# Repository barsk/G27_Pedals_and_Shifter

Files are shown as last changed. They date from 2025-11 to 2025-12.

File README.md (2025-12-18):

# Logitech G27/G29/G920/G923 Pedals and Shifter USB Adapter
*@barsk has taken over as maintainer of this repo after @n-e-y-s. This repo is forked from @functionruturnfunction, https://github.com/functionreturnfunction/G27_Pedals_and_Shifter.*

An USB adapter for the pedals and shifter to bypass the wheel base and treat them as a standalone device. G29/G920/G923 pedals should also work as the DB9 pinout is reportedly the same. Please use the discussions section to **report** wether it works or not with the G29 and later pedals, thanks!

The Logitech Driving Force Shifter used for G29 and later may be supported later, work in progress.

## Latest developments
* The Dpad is now supported as a proper Hat switch (8 directions), instead of 4 buttons!
* Throttle, brake and clutch now uses the axis Rx, Ry and Z so that the joystick control panel test view in Windows presents these in a better way. That has no impact in games as you can map any axis as throttle, brake and clutch.
* A 3D printed box is included in the CAD folder. Use the 3MF file version of the lid if you have a multi color capable printer for a nice text effect. The STL version prints a solid lid with no text.

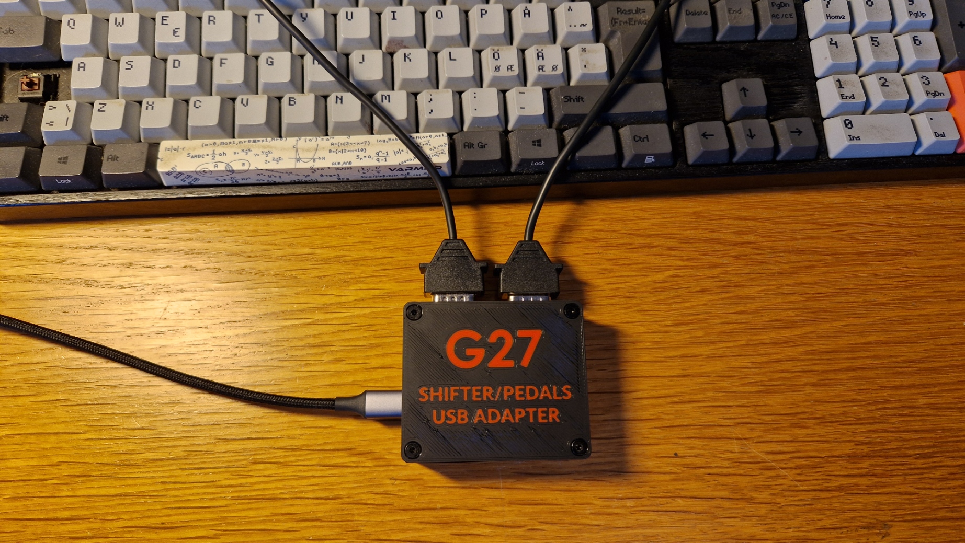
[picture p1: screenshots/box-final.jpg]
printed box

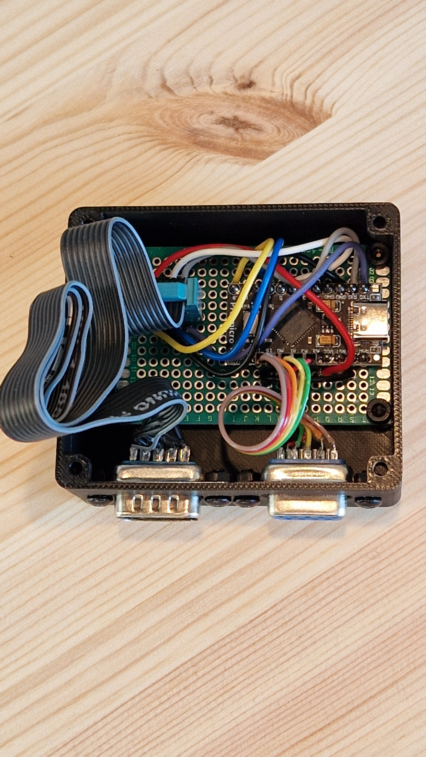
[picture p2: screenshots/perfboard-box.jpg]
on breadboard


Original (older) solution<br>
in altoids tin

## Required Parts/Materials

* [SparkFun Pro Micro](https://www.sparkfun.com/products/12640) or clone (must be a 5V/16MHz ATmega32U4 with onboard USB)
* [DB9 Connectors](http://www.amazon.com/Female-Male-Solder-Adapter-Connectors/dp/B008MU0OR4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), 1 male, 1 female
* Hookup wire in assorted colors
* Some kind of project box. The new 3D printed box or something as an Altoids tin box.
* The 3D printed box requires the use of a common perfboard type I got on Amazon, which is 60 x 40 mm with 20 rows by 14 columns of holes.

## Assembly

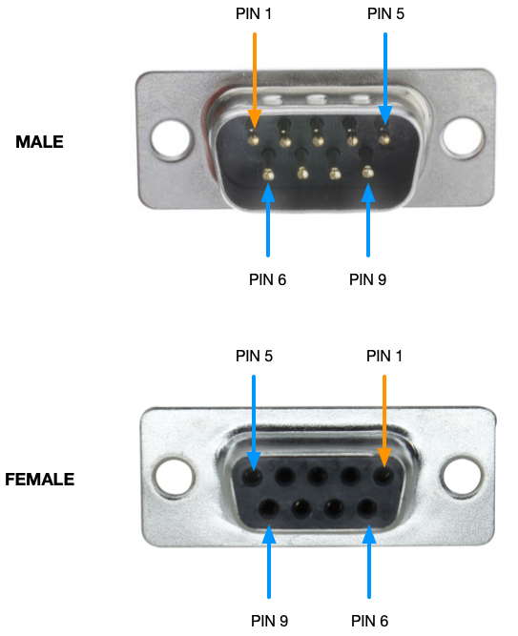
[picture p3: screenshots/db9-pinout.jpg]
DB9 pins


Connect the DB9 pin -> Pro Micro Pin as indicated below.

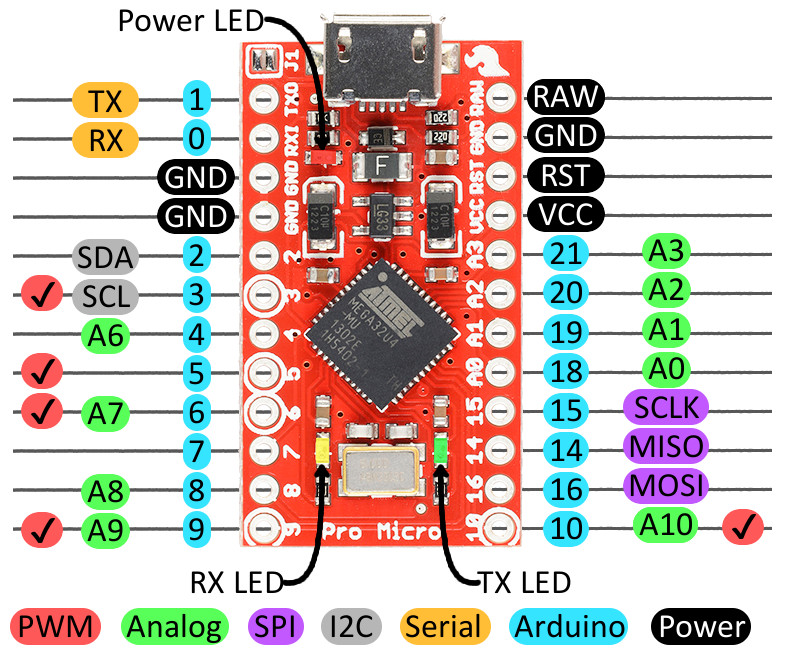
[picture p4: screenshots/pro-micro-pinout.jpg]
  

> [!Note]
> TX**0** = pin **1** and RX**1** = pin **0** on the Pro Micro come in confusing order! Easy to swap those wires!!

### Shifter pins (Male connector)
| DB9 | Color | Shifter | Description | Pro Micro |
| --- | --- | --- | --- | --- |
| 1 | purple | 1 | Button Clock | pin 0  (RX1) |
| 2 | grey | 7 | Button Data | pin 1  (TX0) |
| 3 | white | 5 | Button !CS & !PL (Mode) | pin 4 |
| 4 | blue | 3 | Shifter X axis | pin 8  (A8) |
| 5 | green | 2 | SPI input | |
| 6 | black | 8 | GND | GND |
| 7 | brown | 6 | +5V | VCC |
| 8 | yellow | 4 | Shifter Y axis | pin 9 (A9)  |
| 9 | red | 1 | +5V | VCC |

### Pedal pins (Female connector)
This is the updated wiring suggested by eriknz, which has proper connections to Vcc and GND.<br>
The pedals need to be inverted in the calibration gui.

Connect the female DB9 connector for the pedals to the board using the pins in the table.
| DB9 | Color | Description | Pro Micro |
| --- | --- | --- | --- |
| 1 | black | GND | GND |
| 2 | orange | Throttle | pin 18 (A0) |
| 3 | yellow | Brake | pin 19 (A1) |
| 4 | green | Clutch | pin 20 (A2) |
| 5 | | | |
| 6 | connected *in pedals* plug to pin 9 | (+5V) | |
| 7 | | | |
| 8 | | | |
| 9 | red | +5V | +5V |

## Perfboard and wiring
If a perfboard is used, which is required to fit the 3D printed box, mount the Micro Pro microprocessor board at the topmost row on the 4th column from the left. That will center the USB connector with the hole in the box. Then use the suggested wiring schematic or come up with your own. 

The Fritzing sketch makes the DB9 pins not so clear, which makes this a bit unreadable unfortunately. The important thing here is that the DB pins are connected to the Micro Pro pins in accordance with the table. However the position of the Pro Micro in refrence to the perfboard is physically correct - and should be used if you want to use the printed 3D box.<br>
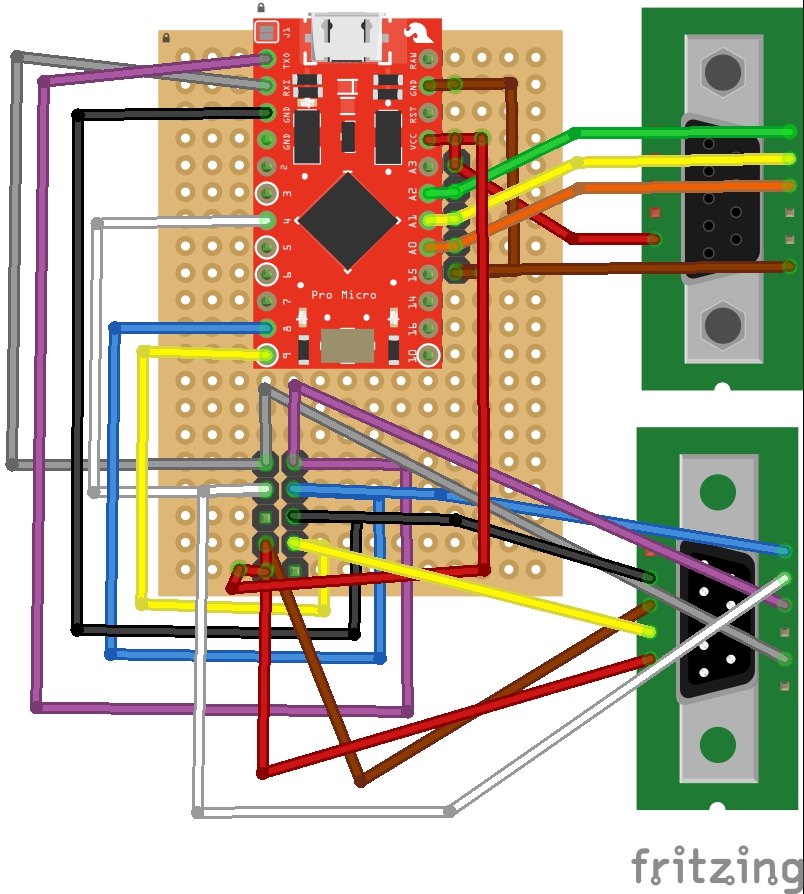
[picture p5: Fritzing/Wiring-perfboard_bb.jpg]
fritzing

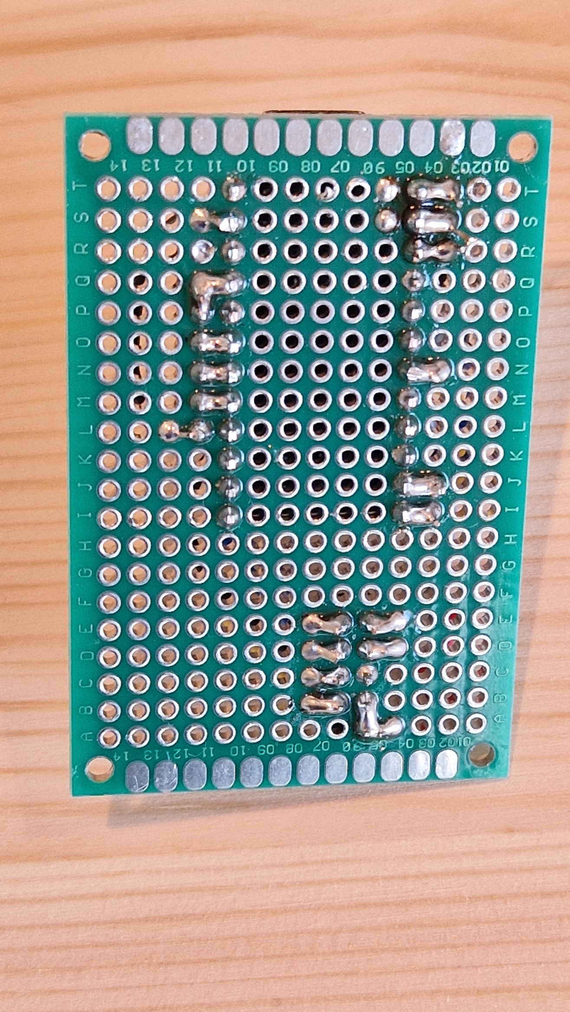
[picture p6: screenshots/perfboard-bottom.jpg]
soldering


## Firmware

Open the .ino file in the Arduino IDE, select the proper board type and COM port under "Tools" (you will need to install the [SparkFun board library](https://github.com/sparkfun/Arduino_Boards)). Also install the Arduino Joystick from MHeironimus.

## Calibration and Configration

After the firmware has been uploaded to the arduino, you want to calibrate and configure the device for your specific device. There is a python based graphical user interface available in this project. 

### GUI installation

#### Using binary releases (windows only)

The easiest method is to download g27calib.zip from the latest release here https://github.com/barsk/G27_Pedals_and_Shifter/releases/latest. Unzip this to a location of your choice and then start g27calib.exe located inside. 

#### Alterantively use python directly

This description assumes a windows operating system (other operating systems are similar; I have tested linux and windows). You need python3 for running this GUI - if you don't have a python3 interpreter on your system already, I suggest to get the interpreter at http://winpython.github.io/. I'd choose the minimal python 3.7 64 bit version, but other versions or distributions should also work. 

The python file *g27calib.py* is in the folder [g27_pedals_and_shifter_gui](g27_pedals_and_shifter_gui). If you have the required libraries installed in Python you may start the tool with:
    
    python g27calib.py

If the tool starts and works, you may also build the .exe (same as in the binary release). First make sure *Pyinstaller* is available and then run Pyinstaller on the supplied spec file.

    pip install pyinstaller
    pyinstaller g27calib.spec

This will create the g27.exe file in the dist subfolder.

#### Other methods
> [!Note]
> This chapter remain from the previous fork and has not been verified by me. I suggest you use the binary release.

When you have a python interpreter in place, I suggest to create a virtual environment using the shell commands:
    
    cd <a path of your choice>
    python -m venv g27calib

This command creates a virtual python environment in the directory g27calib. Afterwards you can install the GUI with 

    .\g27calib\Scripts\pip install git+https://github.com/barsk/G27_Pedals_and_Shifter@master#egg=G27_Pedals_and_Shifter_GUI

Of course you can also specify a local path alternatively to the git path above. Pip downloads some packages from the internet and finally you should be able to start

    g27calib/Scripts/g27calib
    
and the gui should open.

### Calibration process

At first you need to select the Arduino serial device. On linux platforms, it is also necessary to select the joystick device of the G27, otherwise the GUI might be very slow:

device selector

When everything is set correctly, press the Start button. You are presented with the calibration/configuration GUI:

gui screenshot

On the upper right, you get some help text about what to do next. Using that everything shall be pretty self-explaining. The graphs in the lower part are for the pedals and the shifter respectively. You see the measurements over the last second depicted with the "+" marks. 

> [!Note]
> When the GUI mentions you should "move" the shifter with the leftmost red button pressed, it means that the areas you are creating with those movements are the *target area* for the shifter positions. Make sure the areas are large enough to cover the position each gear may have as well as the idle postion, and that no area is too close to another to create a false detection.<br>
When a gear is moved into a target area that will trigger a virtual button to be pressed. Gear 1 pushes button 1 and so on.

The first step is to decide for a suitable filtering. Depending on the wear of your device, the measurements can be quite noisy and so it might be desirable to enable the median filtering in the options panel. When changing the values you will see the immediate effect on the measurements.

> [!Tip]
> If you see a noisy jittery signal from the pedals (and meybe also the shifter), a better solution that filtring is to clean the surfaces of the potentiometers with a can of electronics cleaner spray, which exists for this exact purpose. You will have to open up the casing in order to do get proper access to the potentiometers and spray a small amount inside the pots. I use a Finnish product called "Kontakt PRF 7-78", which cleans and lubricates the carbon surface perfectly, making it as new again and also causing it to have some protection from oxidating again (as it seems in my experience). There is another product called DeOxit that comes in different kinds. You specifically want the F5 one, and not one of the others as those are for connectors, not pots! Some more info here: [YouTube video(]https://www.youtube.com/watch?v=wFP0vSJexFQ)

Note the status line output in the GUI with some profiling output on the left side and the final output values of the axis, buttons and gear value as delivered to the games. 

Last step is to ***save the settings*** to the Arduino's EEPROM using the respective button. You can test that this has been working by going back to the default calibration (plots should change) and then reloading the EEPROM calibration (plots should change to the desired values). Everytime you turn on the Arduino it loads the EEPROM calibration values automatically from now on.

## Known issues
* (see here: https://github.com/n-e-y-s/G27_Pedals_and_Shifter/issues/1): On windows, the arduino will be slow after closing the GUI. To fix that, you can unplug the USB connector and then connect again.
* Since we now have implemented Dpad as a Hat switch, the former implementation that triggered the buttons 10-14 still remains, so those buttons are now "dead". This will not cause any problems, since each used button must be bound in-game anyway. I may fix this in a later release.

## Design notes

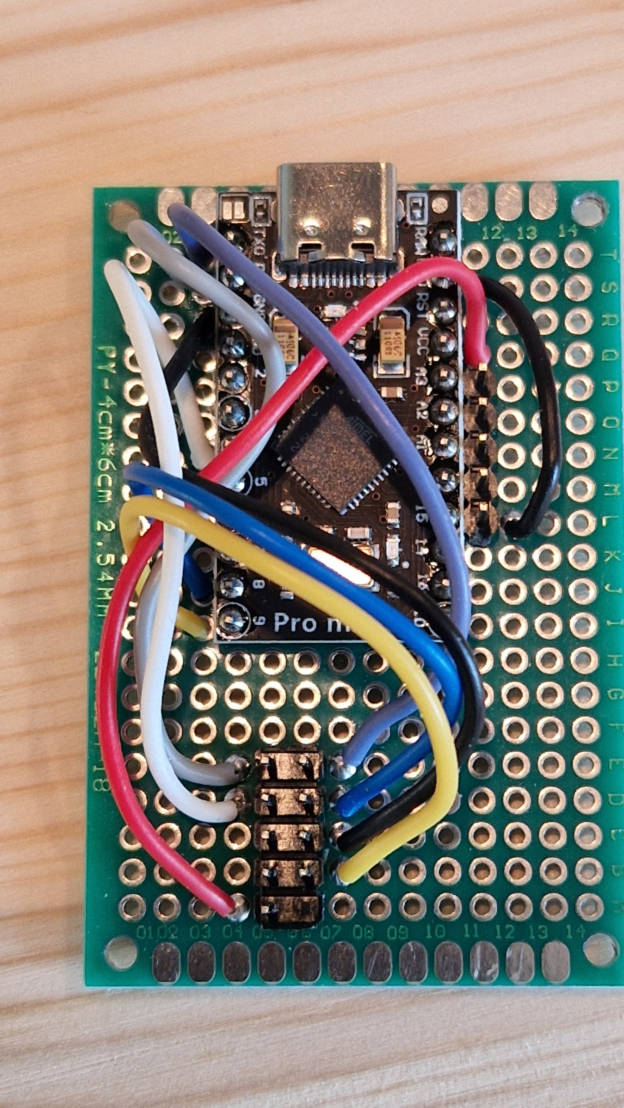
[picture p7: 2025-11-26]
screenshots/perfboard.jpg

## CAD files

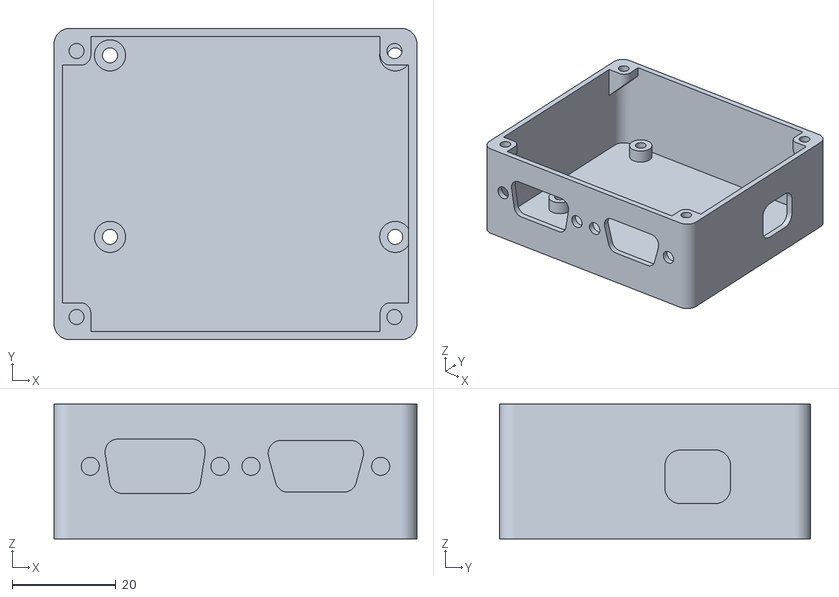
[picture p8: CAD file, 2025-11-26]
CAD/Box.stl
70.0 x 60.0 x 26.0

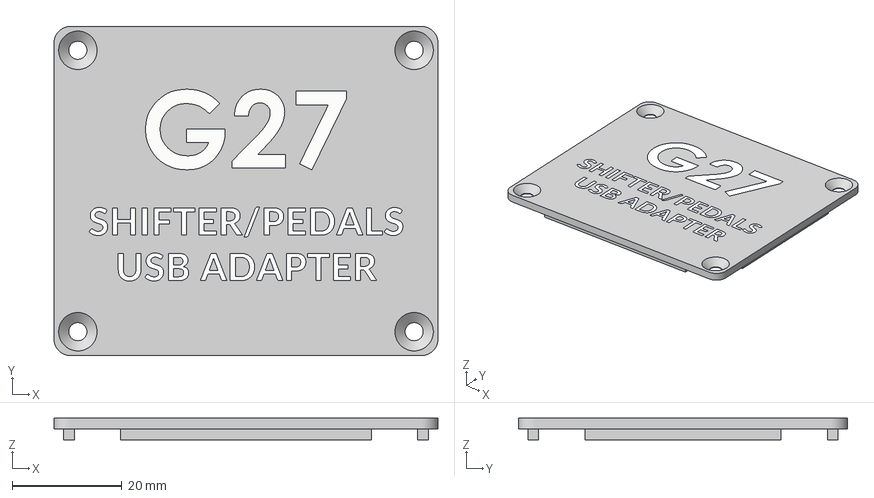
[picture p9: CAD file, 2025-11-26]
CAD/Lid.3mf
70.0 x 60.0 x 4.00 mm
Lid

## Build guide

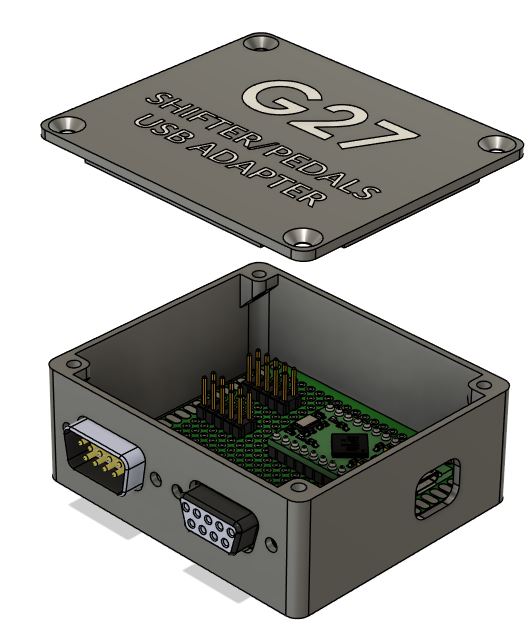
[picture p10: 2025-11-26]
screenshots/printed-box.jpg

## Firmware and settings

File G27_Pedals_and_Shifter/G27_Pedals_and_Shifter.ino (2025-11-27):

// G27_Pedals_and_Shifter.ino
// by Jason Duncan

// Partially adapted from the work done by isrtv.com forums members pascalh and xxValiumxx:
// http://www.isrtv.com/forums/topic/13189-diy-g25-shifter-interface-with-h-pattern-sequential-and-handbrake-modes/

#include <HID.h>
#include <EEPROM.h>
#include <Joystick.h>
#include "./src/Filter.h"

// LED PINS
#define RED_PIN    3
#define GREEN_PIN  5
#define BLUE_PIN   6

// PEDAL PINS - please note the comments of @eriknz in 
// https://github.com/n-e-y-s/G27_Pedals_and_Shifter/issues/8
// This is the wiring suggested by eriknz, which does not connect the pedal ground 
// to +5V (pedals need to be inverted in the calibration gui):
//
//| DB9 | Original | Harness | Description | Pro Micro   |
//|   1 | Black    | Black   | GND         | GND         |
//|   2 | Orange   | Yellow  | Throttle    | pin 18 (A0) |
//|   3 | White    | White   | Brake       | pin 19 (A1) |
//|   4 | Green    | Green   | Clutch      | pin 20 (A2) |
//|   5 |          |         |             |             |
//|   6 | connected in pedals plug to pin 9
//|   7 |          |         |             |             |
//|   8 |          |         |             |             |
//|   9 | Red      | Red     | +5V         | +5V         |
//
// This is the original wiring from @functionreturnfunction
//
//| DB9 | Original | Harness | Description | Pro Micro   |
//|   1 | Black    | Red     | +5v         | +5v         |
//|   2 | Orange   | Yellow  | Throttle    | pin 18 (A0) |
//|   3 | White    | White   | Brake       | pin 19 (A1) |
//|   4 | Green    | Green   | Clutch      | pin 20 (A2) |
//|   5 |          |         |             |             |
//|   6 | Red      | Black   | GND         | GND         |
//|   7 |          |         |             |             |
//|   8 |          |         |             |             |
//|   9 | Red      | Black   | GND         | GND         |
#define GAS_PIN    18
#define BRAKE_PIN  19
#define CLUTCH_PIN 20

// SHIFTER PINS
//| DB9 | Original | Harness | Shifter | Description             | Pro Micro   |
//|   1 | Purple   | Purple  |       1 | Button Clock            | pin 0       |
//|   2 | Grey     | Blue    |       7 | Button Data             | pin 1       |
//|   3 | Yellow   | Yellow  |       5 | Button !CS & !PL (Mode) | pin 4       |
//|   4 | Orange   | Orange  |       3 | Shifter X axis          | pin 8  (A8) |
//|   5 | White    | White   |       2 | SPI input               |             |
//|   6 | Black    | Black   |       8 | GND                     | GND         |
//|   7 | Red      | Red     |       6 | +5V                     | VCC         |
//|   8 | Green    | Green   |       4 | Shifter Y axis          | pin 9 (A9)  |
//|   9 | Red      | Red     |       1 | +5V                     | VCC         |
#define SHIFTER_CLOCK_PIN  0
#define SHIFTER_DATA_PIN   1
#define SHIFTER_MODE_PIN   4
#define SHIFTER_X_PIN      8
#define SHIFTER_Y_PIN      9

// BUTTON DEFINITIONS
#define BUTTON_REVERSE         1

#define BUTTON_RED_CENTERRIGHT 4
#define BUTTON_RED_CENTERLEFT  5
#define BUTTON_RED_RIGHT       6
#define BUTTON_RED_LEFT        7
#define BUTTON_BLACK_TOP       8
#define BUTTON_BLACK_RIGHT     9
#define BUTTON_BLACK_LEFT      10
#define BUTTON_BLACK_BOTTOM    11
#define BUTTON_DPAD_RIGHT      12
#define BUTTON_DPAD_LEFT       13
#define BUTTON_DPAD_BOTTOM     14
#define BUTTON_DPAD_TOP        15

// Gears are mapped to output 0-6

#define OUTPUT_BLACK_TOP       7
#define OUTPUT_BLACK_LEFT      8
#define OUTPUT_BLACK_RIGHT     9
#define OUTPUT_BLACK_BOTTOM    10
#define OUTPUT_DPAD_TOP        11
#define OUTPUT_DPAD_LEFT       12
#define OUTPUT_DPAD_RIGHT      13
#define OUTPUT_DPAD_BOTTOM     14
#define OUTPUT_RED_LEFT        15
#define OUTPUT_RED_CENTERLEFT  16
#define OUTPUT_RED_CENTERRIGHT 17
#define OUTPUT_RED_RIGHT       18

// MISC.
#define MAX_AXIS            1023
#define SIGNAL_SETTLE_DELAY 10

#define CALIB_DATA_MAGIC_NUMBER 0x27CA11B1 // change this when the struct definition changes

#define FLAG1_INVERT_BRAKE 0x1 // invert brake pedal
#define FLAG1_INVERT_GAS 0x2 // invert gas pedal
#define FLAG1_INVERT_CLUTCH 0x4 // invert clutch pedal
#define FLAG1_REVERSE_RIGHT_RED 0x8 // use right red button for reverse gear instead of the reverse sensor
#define FLAG1_COMBINE_Z_EQUALS_X_MINUS_Z 0x10 // combine clutch and gas
#define FLAG1_COMBINE_Z_EQUALS_Z_MINUS_X 0x20 // combine clutch and gas

#define FLAG2_ENABLE_PEDALS 0x1
#define FLAG2_BRAKE_DEAD_ZONE (0x2|0x4|0x8) // deadZone_percent = ((flag & FLAG2_BRAKE_DEAD_ZONE) >> 1)*2
#define FLAG2_GAS_DEAD_ZONE (0x10|0x20|0x40) // deadZone_percent = ((flag & FLAG2_GAS_DEAD_ZONE) >> 4)*2

#define FLAG3_ENABLE_SHIFTER 0x1
#define FLAG3_CLUTCH_DEAD_ZONE (0x10|0x20|0x40) // deadZone_percent = ((flag & FLAG3_CLUTCH_DEAD_ZONE) >> 4)*2

Joystick_ G27(            // define Joystick parameters
  5,  
  JOYSTICK_TYPE_JOYSTICK,      // type Joystick
  19, 1,                       // Button Count, Hat Switch Count
  false, false, true,               // X, Y, Z
  true,true,false,                  // Rx, Ry, Rz
  false,false,false,false,false);   // Throttle, Rudder, Accelerator, Brake, Steering 

typedef struct CalibData
{
  /* magic number, used for testing valid EEPROM content */
  uint32_t calibID;
  /* bool whether to automatically calibrate the pedals at a power cycle or use a static calibration */
  uint8_t pedals_auto_calib; 
  /* flag1, see the FLAG1_* defines for the meaning of the bits */
  uint8_t flag1;
  /* flag2, see the FLAG2_* defines for the meaning of the bits */
  uint8_t flag2;
  /* flag3, see the FLAG3_* defines for the meaning of the bits */
  uint8_t flag3;
  /* size of median filter to filter pedal values */
  uint8_t pedal_median_size;
  /* size of median filter to filter shifter values */
  uint8_t shifter_median_size;
  /* only meaningful if pedals_auto_calib is 0 */
  uint16_t gasMin, gasMax, brakeMin, brakeMax, clutchMin, clutchMax;
  /* defines the neutral zone of the y shifter hysteresis */
  uint16_t shifter_y_neutralMin, shifter_y_neutralMax;
  /* defines the 246R zone of the y shifter hysteresis, should be less than shifter_y_neutralMin */
  uint16_t shifter_y_246R_gearZone;
  /* defines the 135 zone of the y shifter hysteresis, should be greater than shifter_y_neutralMax */
  uint16_t shifter_y_135_gearZone;
  /* threshold for gears 1 and 2 of the x shifter, should be less than shifter_x_56 */
  uint16_t shifter_x_12;
  /* threshold for gears 5,6 and R of the x shifter, should be greater than shifter_x_12 */
  uint16_t shifter_x_56;  
} CalibData;

/* this structure holds the calibration data stored in EEPROM */
typedef struct calibration
{
    /* the actual calibration struct */
    CalibData data;
    /* CRC checksum */
    uint32_t crc;
} Calibration;

static Calibration calibDefault = {
    {
        CALIB_DATA_MAGIC_NUMBER,
        1, /* pedals auto calib */
        0, /* flag1, everything on default */
        1, /* use pedals */
        1, /* use shifter */
        0, /* pedals median size */
        0, /* shifter median size */
        0,0,0,0,0,0, /* calibrated pedal values */
        1024/2 - 1024/10, 1024/2 + 1024/10, /* shifter_y_neutral */
        1024/2 - 1024/3, 1024/2 + 1024/3,   /* shifter_y_gearZone */
        1024/3, 1024*2/3 /* shifter_x */
    },
    0 /* crc will be set when written to EEPROM */
};
static Calibration calibration = calibDefault;

unsigned long crc(uint8_t *buffer, uint16_t length) {

  const unsigned long crc_table[16] = {
    0x00000000, 0x1db71064, 0x3b6e20c8, 0x26d930ac,
    0x76dc4190, 0x6b6b51f4, 0x4db26158, 0x5005713c,
    0xedb88320, 0xf00f9344, 0xd6d6a3e8, 0xcb61b38c,
    0x9b64c2b0, 0x86d3d2d4, 0xa00ae278, 0xbdbdf21c
  };

  unsigned long crc = ~0L;

  for (uint8_t index = 0 ; index < length ; ++index) {
    crc = crc_table[(crc ^ buffer[index]) & 0x0f] ^ (crc >> 4);
    crc = crc_table[(crc ^ (buffer[index] >> 4)) & 0x0f] ^ (crc >> 4);
    crc = ~crc;
  }
  return crc;
}

static int crcError = 0;
static int magicNumberError = 0;
static int lastCrcFromEEPROM = 0;
static int lastCrcFromContents = 0;

void loadEEPROM()
{
  Calibration fromEEPROM;
  EEPROM.get(0, fromEEPROM);
  
  uint32_t eeprom_crc = crc((uint8_t*)&fromEEPROM.data, sizeof(fromEEPROM.data));
  lastCrcFromEEPROM = fromEEPROM.crc;
  lastCrcFromContents = eeprom_crc;
  if( eeprom_crc == fromEEPROM.crc && fromEEPROM.data.calibID == CALIB_DATA_MAGIC_NUMBER )
  {
    calibration = fromEEPROM;
  } else
  {
    crcError += eeprom_crc != fromEEPROM.crc;
    magicNumberError += fromEEPROM.data.calibID != CALIB_DATA_MAGIC_NUMBER;
    calibration = calibDefault;
  }
}

// PEDAL CODE
typedef struct Pedal {
  byte pin;
  int min, max, cur, axis;
} Pedal;

static Pedal* gasPedal = 0;
static Pedal* brakePedal = 0;
static Pedal* clutchPedal = 0;

int axisValue(struct Pedal* input, int dead_zone) 
{
  int physicalRange = input->max - input->min;
  int delta = dead_zone == 0 ? 0 : ((int32_t)physicalRange*(int32_t)dead_zone/(int32_t)100);
  int max = input->max - delta;
  int min = input->min + delta;
  physicalRange = max - min;
  if (physicalRange == 0) {
    return 0;
  }

  int result = map(input->cur, min, max, 0, MAX_AXIS);

  if (result < 0) {
    return 0;
  }
  if (result > MAX_AXIS) {
    return MAX_AXIS;
  }
  return result;
}

void processPedal(struct Pedal* input, SignalFilter *flt, uint8_t filterSize, int dead_zone) 
{
  input->cur = apply_filter(flt, filterSize, analogRead(input->pin));

  if(calibration.data.pedals_auto_calib)
  {
    // calibrate, we want the highest this pedal has been
    input->max = input->cur > input->max ? input->cur : input->max;
    // same for lowest, but bottom out at current value rather than 0
    input->min = input->cur < input->min ? input->cur : input->min;
  }

  input->axis = axisValue(input, dead_zone);
}

void setXAxis(void* in) {
  Pedal* input = (Pedal*)in;
  G27.setRxAxis(input->axis);
}

void setYAxis(void* in) {
  Pedal* input = (Pedal*)in;
  G27.setRyAxis(input->axis);
}

void setZAxis(void* in) {
  Pedal* input = (Pedal*)in;
  G27.setZAxis(input->axis);
}

// SHIFTER CODE
int buttonTable[] = {
  // first four are unused
  0, 0, 0, 0,
  OUTPUT_RED_CENTERRIGHT,
  OUTPUT_RED_CENTERLEFT,
  OUTPUT_RED_RIGHT,
  OUTPUT_RED_LEFT,
  OUTPUT_BLACK_TOP,
  OUTPUT_BLACK_RIGHT,
  OUTPUT_BLACK_LEFT,
  OUTPUT_BLACK_BOTTOM,
  OUTPUT_DPAD_RIGHT,
  OUTPUT_DPAD_LEFT,
  OUTPUT_DPAD_BOTTOM,
  OUTPUT_DPAD_TOP
};

void waitForSignalToSettle() {
  delayMicroseconds(SIGNAL_SETTLE_DELAY);
}

void getButtonStates(int *ret) {
  digitalWrite(SHIFTER_MODE_PIN, LOW);    // Switch to parallel mode: digital inputs are read into shift register
  waitForSignalToSettle();
  digitalWrite(SHIFTER_MODE_PIN, HIGH);   // Switch to serial mode: one data bit is output on each clock falling edge

  for(int i = 0; i < 16; ++i) {           // Iteration over both 8 bit registers
    digitalWrite(SHIFTER_CLOCK_PIN, LOW);         // Generate clock falling edge
    waitForSignalToSettle();

    ret[i] = digitalRead(SHIFTER_DATA_PIN);

    digitalWrite(SHIFTER_CLOCK_PIN, HIGH);        // Generate clock rising edge
    waitForSignalToSettle();
  }
}

void getShifterPosition(int *ret) {
  ret[0] = analogRead(SHIFTER_X_PIN);
  ret[1] = analogRead(SHIFTER_Y_PIN);
}

int getCurrentGear(int shifterPosition[], int btns[]) {
  static int gear = 0;  // default to neutral
  uint16_t x = shifterPosition[0], y = shifterPosition[1];
  
  if (y < calibration.data.shifter_y_neutralMax && y > calibration.data.shifter_y_neutralMin)
  {
    gear = 0;
  }

  if (y > calibration.data.shifter_y_135_gearZone )
  {
    if( x <= calibration.data.shifter_x_12 )
    {
      if( gear != 3 ) /* avoid toggles between neighboring gears */
      {
        gear = 1;
      }
    } else if ( x >= calibration.data.shifter_x_56 )
    {
      if( gear != 3 ) /* avoid toggles between neighboring gears */
      {
        gear = 5;
      }
    } else
    {
      if( gear != 1 && gear != 5 ) /* avoid toggles between neighboring gears */
      {
        gear = 3;
      }
    }
  }
  if (y < calibration.data.shifter_y_246R_gearZone )
  {
    if( x <= calibration.data.shifter_x_12 )
    {
      if( gear != 4 ) /* avoid toggles between neighboring gears */
      {
        gear = 2;
      }
    } else if ( x >= calibration.data.shifter_x_56 )
    {
      uint8_t reverse = (calibration.data.flag1 & FLAG1_REVERSE_RIGHT_RED) ? btns[BUTTON_RED_RIGHT] : btns[BUTTON_REVERSE];
      if(reverse)
      {
        if( gear != 4 && gear != 6 ) /* avoid toggles between neighboring gears */
        {
          gear = 7;
        }
      } else
      {
        if( gear != 4 && gear != 7) /* avoid toggles between neighboring gears */
        {
          gear = 6;
        }
      }
    } else
    {
      if( gear != 2 && gear != 6  && gear != 7) /* avoid toggles between neighboring gears */
      {
        gear = 4;
      }
    }
  }
  // reset button if we are not in reverse gear (this was there in original code, not sure if it's needed)
  if (gear != 7) btns[BUTTON_REVERSE] = 0;

  return gear;
}

typedef struct DebugStruct
{
  uint8_t sizeInBytes;
  uint8_t calibButton;
  int16_t axisValues[5];
  CalibData calib;
  uint16_t numCrcErrors;
  uint16_t numMagicNumErrors;
  uint32_t profiling[4];
  uint16_t out_axis[3];
  uint32_t out_buttons;
} DebugStruct;

static DebugStruct debug = {0};

void setButtonStates(int buttons[], int gear) {
  // SHIFTER CODE
  debug.out_buttons = 0;
  
  // release virtual buttons for all gears
  for (byte i = 0; i < 7; ++i) {
    G27.setButton(i, LOW);
  }

  if (gear > 0) {
    G27.setButton(gear - 1, HIGH);
    debug.out_buttons |= 1 << (gear - 1);
  }

  for (byte i = BUTTON_RED_CENTERRIGHT; i <= BUTTON_BLACK_BOTTOM; ++i) {
    G27.setButton(buttonTable[i], buttons[i]);
    if( buttons[i] )
    {
      debug.out_buttons |= 1 << buttonTable[i];
    }
  }

  // Hat switch (D-Pad)
  byte hatSwitchState = 0;
  hatSwitchState |= (buttons[BUTTON_DPAD_TOP] << 0);
  hatSwitchState |= (buttons[BUTTON_DPAD_RIGHT] << 1);
  hatSwitchState |= (buttons[BUTTON_DPAD_BOTTOM] << 2);
  hatSwitchState |= (buttons[BUTTON_DPAD_LEFT] << 3);

  switch (hatSwitchState)
  {
  case 0B00000001:
    G27.setHatSwitch(0, 0); // up
    break;
  case 0B00000011:
    G27.setHatSwitch(0, 45); // up right
    break;
  case 0B00000010:
    G27.setHatSwitch(0, 90); // right
    break;
  case 0B00000110:
    G27.setHatSwitch(0, 135); // down right
    break;
  case 0B00000100:
    G27.setHatSwitch(0, 180); // down
    break;
  case 0B00001100:
    G27.setHatSwitch(0, 225); // down left
    break;
  case 0B00001000:
    G27.setHatSwitch(0, 270); // left
    break;
  case 0B00001001:
    G27.setHatSwitch(0, 315); // up left
    break;
  case 0B00000000:
    G27.setHatSwitch(0, -1); // no direction
  default:
    break;
  }
}

void set_dead_zone(uint8_t dz, int pedal, CalibData *calib)
{
    dz /= 2;
    switch(pedal)
    {
        case 0:
            calib->flag2 &= ~(FLAG2_GAS_DEAD_ZONE);
            calib->flag2 |= (dz) << 4;
            break;
        case 1:
            calib->flag2 &= ~(FLAG2_BRAKE_DEAD_ZONE);
            calib->flag2 |= (dz) << 1;
            break;
        case 2:
            calib->flag3 &= ~(FLAG3_CLUTCH_DEAD_ZONE);
            calib->flag3 |= (dz) << 4;
            break;
        default:
          break;
    }
}

#define CALIB_MIN(calibValue, curValue, minValue) if( (int)calibValue < 0 || (int)curValue < (int)minValue ) { calibValue = minValue = curValue; }
#define CALIB_MAX(calibValue, curValue, maxValue) if( (int)calibValue < 0 || (int)curValue > (int)maxValue ) { calibValue = maxValue = curValue; }
#define CALIB_RANGE(calibValue, curValue, minValue, maxValue) \
    { if( (int)calibValue < 0 ) { calibValue = minValue = maxValue = curValue; } \
      CALIB_MIN(calibValue, curValue, minValue); \
      CALIB_MAX(calibValue, curValue, maxValue); }
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
void loop() {
  debug.profiling[2] = micros();
  // pedals
  processPedal(gasPedal, &signalFilters[0], calibration.data.pedal_median_size, 
               ((calibration.data.flag2 & FLAG2_GAS_DEAD_ZONE) >> 4)*2);
  processPedal(brakePedal, &signalFilters[1], calibration.data.pedal_median_size,
               ((calibration.data.flag2 & FLAG2_BRAKE_DEAD_ZONE) >> 1)*2);
  processPedal(clutchPedal, &signalFilters[2], calibration.data.pedal_median_size,
               ((calibration.data.flag3 & FLAG3_CLUTCH_DEAD_ZONE) >> 4)*2);

  if(calibration.data.flag1 & FLAG1_INVERT_GAS )
  {
    Pedal* gas = (Pedal*)gasPedal;
    gas->axis = map(gas->axis, 0, MAX_AXIS, MAX_AXIS, 0);
  }
  if(calibration.data.flag1 & FLAG1_INVERT_BRAKE )
  {
    Pedal* brake = (Pedal*)brakePedal;
    brake->axis = map(brake->axis, 0, MAX_AXIS, MAX_AXIS, 0);
  }
  if(calibration.data.flag1 & FLAG1_INVERT_CLUTCH )
  {
    Pedal* clutch = (Pedal*)clutchPedal;
    clutch->axis = map(clutch->axis, 0, MAX_AXIS, MAX_AXIS, 0);
  }
  if(calibration.data.flag1 & FLAG1_COMBINE_Z_EQUALS_X_MINUS_Z)
  {
      Pedal *clutch = (Pedal*)clutchPedal;
      Pedal *gas = (Pedal*)gasPedal;
      clutch->axis = map(gas->axis - clutch->axis, -MAX_AXIS, MAX_AXIS, 0, MAX_AXIS);
  }
  if(calibration.data.flag1 & FLAG1_COMBINE_Z_EQUALS_Z_MINUS_X)
  {
      Pedal *clutch = (Pedal*)clutchPedal;
      Pedal *gas = (Pedal*)gasPedal;
      clutch->axis = map(clutch->axis - gas->axis, -MAX_AXIS, MAX_AXIS, 0, MAX_AXIS);
  }

  if(calibration.data.flag2 & FLAG2_ENABLE_PEDALS)
  {
    setXAxis(gasPedal);
    setYAxis(brakePedal);
    setZAxis(clutchPedal);
    debug.out_axis[0] = gasPedal->axis;
    debug.out_axis[1] = brakePedal->axis;
    debug.out_axis[2] = clutchPedal->axis;
  } else
  {
    debug.out_axis[0] = 0xffff;
    debug.out_axis[1] = 0xffff;
    debug.out_axis[2] = 0xffff;
  }
  
  // shifter
  int buttonStates[16];
  getButtonStates(buttonStates);
  
  int shifterPosition[2];
  getShifterPosition(shifterPosition);
  shifterPosition[0] = apply_filter(&signalFilters[3], calibration.data.shifter_median_size, shifterPosition[0]);
  shifterPosition[1] = apply_filter(&signalFilters[4], calibration.data.shifter_median_size, shifterPosition[1]);
  
  int gear = getCurrentGear(shifterPosition, buttonStates);

  if(calibration.data.flag3 & FLAG3_ENABLE_SHIFTER)
  {
    setButtonStates(buttonStates, gear);
  } else
  {
    debug.out_buttons = 0xffffffff;
  }

  calib(gasPedal, brakePedal, clutchPedal, shifterPosition[0], shifterPosition[1], buttonStates[BUTTON_RED_LEFT]);
  G27.sendState();
  debug.profiling[1] = micros();
}

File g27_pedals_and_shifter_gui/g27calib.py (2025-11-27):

import struct
import ctypes as ct
import sys
import time
import os
import traceback
from PySide2.QtCore import QRectF, Qt, QObject, QThread, Signal, QMutex, QMutexLocker, QTimer, QSignalBlocker
from PySide2.QtGui import QBrush, QPen, QColor
from PySide2.QtWidgets import (QApplication, QWidget, QGroupBox, QLabel, QGridLayout, QVBoxLayout, QRadioButton,
                               QCheckBox, QComboBox, QPushButton)
import serial
from serial.tools import list_ports
import pyqtgraph as pg
import numpy as np
# all joystick inputs seem to have issues with the more than 16 buttons present on G27 shifter.
# therefore, we just use inputs to connect to the device and all other stuff is transferred via serial
# port.
import inputs

FLAG1_INVERT_BRAKE = 0x1
FLAG1_INVERT_GAS = 0x2
FLAG1_INVERT_CLUTCH = 0x4
FLAG1_REVERSE_RIGHT_RED = 0x8
FLAG1_COMBINE_Z_EQUALS_X_MINUS_Z = 0x10
FLAG1_COMBINE_Z_EQUALS_Z_MINUS_X = 0x20
FLAG2_ENABLE_PEDALS = 0x1
FLAG2_BRAKE_DEAD_ZONE = (0x2|0x4|0x8)
FLAG2_GAS_DEAD_ZONE = (0x10|0x20|0x40)
FLAG3_ENABLE_SHIFTER = 0x1
FLAG3_CLUTCH_DEAD_ZONE = (0x10|0x20|0x40)

# following structures need to be synchronized with Arduino C Code
class CalibData(ct.Structure):
    _pack_ = 2
    _fields_ = [
        ("calibID", ct.c_uint32),
        ("pedals_auto_calib", ct.c_uint8),
        ("flag1", ct.c_uint8),
        ("flag2", ct.c_uint8),
        ("flag3", ct.c_uint8),
        ("pedals_median_size", ct.c_uint8),
        ("shifter_median_size", ct.c_uint8),
        ("gasMin", ct.c_uint16),
        ("gasMax", ct.c_uint16),
        ("brakeMin", ct.c_uint16),
        ("brakeMax", ct.c_uint16),
        ("clutchMin", ct.c_uint16),
        ("clutchMax", ct.c_uint16),
        ("shifter_y_neutralMin", ct.c_uint16),
        ("shifter_y_neutralMax", ct.c_uint16),
        ("shifter_y_246R_gearZone", ct.c_uint16),
        ("shifter_y_135_gearZone", ct.c_uint16),
        ("shifter_x_12", ct.c_uint16),
        ("shifter_x_56", ct.c_uint16),
    ]

class DebugStruct(ct.Structure):
    _pack_ = 2
    _fields_ = [
        ("sizeInBytes", ct.c_uint8),
        ("calibButton", ct.c_uint8),
        ("axisValues", ct.c_uint16*5),
        ("calib", CalibData),
        ("numCrcErrors", ct.c_uint16),
        ("numMagicNumErrors", ct.c_uint16),
        ("profiling", ct.c_uint32*4),
        ("out_axis", ct.c_uint16*3),
        ("out_buttons", ct.c_uint32)
    ]


class Values:
    def __init__(self, history_time_s = 1.0):
        self.mutex = QMutex()
        self.history_time_ns = np.int64(history_time_s*1e9)
        self.times = np.zeros((0,), dtype=np.int64)
        self.gas = np.zeros((0,), dtype=np.uint16)
        self.brake = np.zeros((0,), dtype=np.uint16)
        self.clutch = np.zeros((0,), dtype=np.uint16)
        self.sx = np.zeros((0,), dtype=np.uint16)
        self.sy = np.zeros((0,), dtype=np.uint16)
        self.calib = CalibData()

    def update(self, dbg): # options
        ml = QMutexLocker(self.mutex)
        self.times = np.append(self.times, [time.perf_counter_ns()])
        v = self.times >= self.times[-1] - self.history_time_ns
        self.times = self.times[v]
        self.gas = np.append(self.gas, [dbg.axisValues[2]])[v]
        self.brake = np.append(self.brake, [dbg.axisValues[3]])[v]
        self.clutch = np.append(self.clutch, [dbg.axisValues[4]])[v]
        self.sx = np.append(self.sx, [dbg.axisValues[0]])[v]
        self.sy = np.append(self.sy, [dbg.axisValues[1]])[v]
        self.calib = dbg.calib

    def add(self, other):
        ml = QMutexLocker(other.mutex)
        ml2 = QMutexLocker(self.mutex)
        self.times = np.append(self.times, other.times)
        self.gas = np.append(self.gas, other.gas)
        self.brake = np.append(self.brake, other.brake)
        self.clutch = np.append(self.clutch, other.clutch)
        self.sx = np.append(self.sx, other.sx)
        self.sy = np.append(self.sy, other.sy)
        self.calib = other.calib
        other.times = np.resize(other.times, (0,))
        other.gas = np.resize(other.gas, (0,))
        other.brake = np.resize(other.brake, (0,))
        other.clutch = np.resize(other.clutch, (0,))
        other.sx = np.resize(other.sx, (0,))
        other.sy = np.resize(other.sy, (0,))
        v = self.times >= self.times[-1] - self.history_time_ns
        self.times = self.times[v]
        self.gas = self.gas[v]
        self.brake = self.brake[v]
        self.clutch = self.clutch[v]
        self.sx = self.sx[v]
        self.sy = self.sy[v]

class G27CalibGui(QWidget):
    sendModeCmd = Signal(object)
    setObjectCmd = Signal(object)
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

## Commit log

2025-11-26 New 3D printed box Updated docs
    [Box.stl, Lid.3mf, Wiring-perfboard.fzz]
2025-11-27 Code cleanup Using the Arduino Joystick library instead of custom HID implementation. Changed Throttle and Brake axis to Rx, Ry respectively. The DPAD is now interpreted as a Hat Switch instead of 4 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
2025-11-27 Updated README with perfboard and wiring guide.
    [Wiring-perfboard.fzz]
2025-11-27 Updated READMe with perfboard and wiring info
2025-12-17 Clarify DB9 pinout and wiring instructions
    Updated the DB9 pinout instructions and clarified wiring notes.
